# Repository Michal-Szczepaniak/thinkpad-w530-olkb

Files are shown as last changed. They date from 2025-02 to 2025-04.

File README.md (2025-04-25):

# Thinkpad OLKB Preonic keybaord pcb

Get it printed and enjoy.

USB can be connected in multiple ways:

- Directly into the MCU thanks to open space near it
- After soldering the bottom pads, via available pins next to the usb port
- After soldering the bottom pads and FPC connector, via FPC connector

USB can be fetched from multiple places, the lower end the laptop (x series) the less options so I'll list all the w530 options:

- Bluetooth connector, if you swapped wifi card for wifi+bt you aren't using the standalone bt so you can get usb from there
- msata, its next to the open hole for the usb, with msata to usb converter you can either just plug in short cable from msata directly to mcu (easiest possible connection) or you can cut the microusb end and solder it to pins or desolder the usb and route it with wires
- Smartcard fpc connector, it's located at the bottom middle of the motheboard next to the bios chips underneath the touchpad. Thats what the FPC connector on keyboard is for, you can buy 6 pin 0.5mm pitch FPC cable and connect it. Watch out though because it has 5V 15A unfused and if you short it you will instantly kill the laptop, but the keyboard has fuse which protects it, but only if something happens AFTER the fuse so isolate the fpc connector pins.
- Fingerprint/color sensor usb FPC, they're both just usb's on FPC tape, so you can use that, although they might not be directly pluggable into keyboard's FPC connector, I don't know their pinout as I was targetting the Smartcard FPC connector.

Power button is connected via mounting OG keyboard's FPC tape or soldering it, you can pick either option by soldering the pads next to the FPC pins. Make sure you pick correct option otherwise you can short something. Power button is also routed to the mcu pin in case you want that, although when laptop is off, they keyboard is off unless you route always-on 5V to it.

There are pins for connecting Framework touchpad, if you go this route, just wire them to the test pads on the Framework's touchpad and that's it. If you want to use Framework's touchpad and mount it by demeling the case then you need to break out the touchpad pcb extension.

There's hole for a keyboard mounting screw, M2x20 and use a nut to hold it down but don't overtighten it!

Oh also cake the bottom in electrical tape and make sure there are no pointy solder points, otherwise it will short out on the aluminum case which is less than ideal.

As of now the space above keyboard is not covered by anything which is KIIIIIIINDA sketchy but can be covered with electrical tape or simple 3D print. If you don't use the hole for usb cable that one can also be covered via electrical tape.

# 3D Printable blanks

Because the keyboard has gaping hole in the middle for the usb cable and also gaping hole above it, there are 3D printable blanks that can be put in place to protect anything below. Also if you decide to mod the touchpad I've included the touchpad buttons blank. [Blanks directory](https://github.com/Michal-Szczepaniak/thinkpad-w530-olkb)

# BOM 

- FPC 6PIN 0.5mm pitch, opposite side. Also please be careful because if you wire it incorrectly you'll instantly fry the motherboard.
- 6 pin FPC connector - DS1020-11-6VBT1-R
- Raspberry pi pico
- PG1425 switches
- Either THT or SMD diodes - THT you can handle, SMD 1N4148WS-DIO (SOD323F)
- Patience

# Palm rejection not working 

By default both framework touchpad and this keyboard are treated as external devices so we have to tell libinput that they're in fact not.

Create file `/etc/libinput/local-overrides.quirks` with content:
```
[Keyboards]
MatchUdevType=keyboard
MatchName=QMK Macroboard
AttrKeyboardIntegration=internal

[Touchpad]
MatchUdevType=touchpad
MatchName=QMK Macroboard Touchpad
AttrKeyboardIntegration=internal
```

And enable palm rejection. Voila!

# Gallery

## Schematic

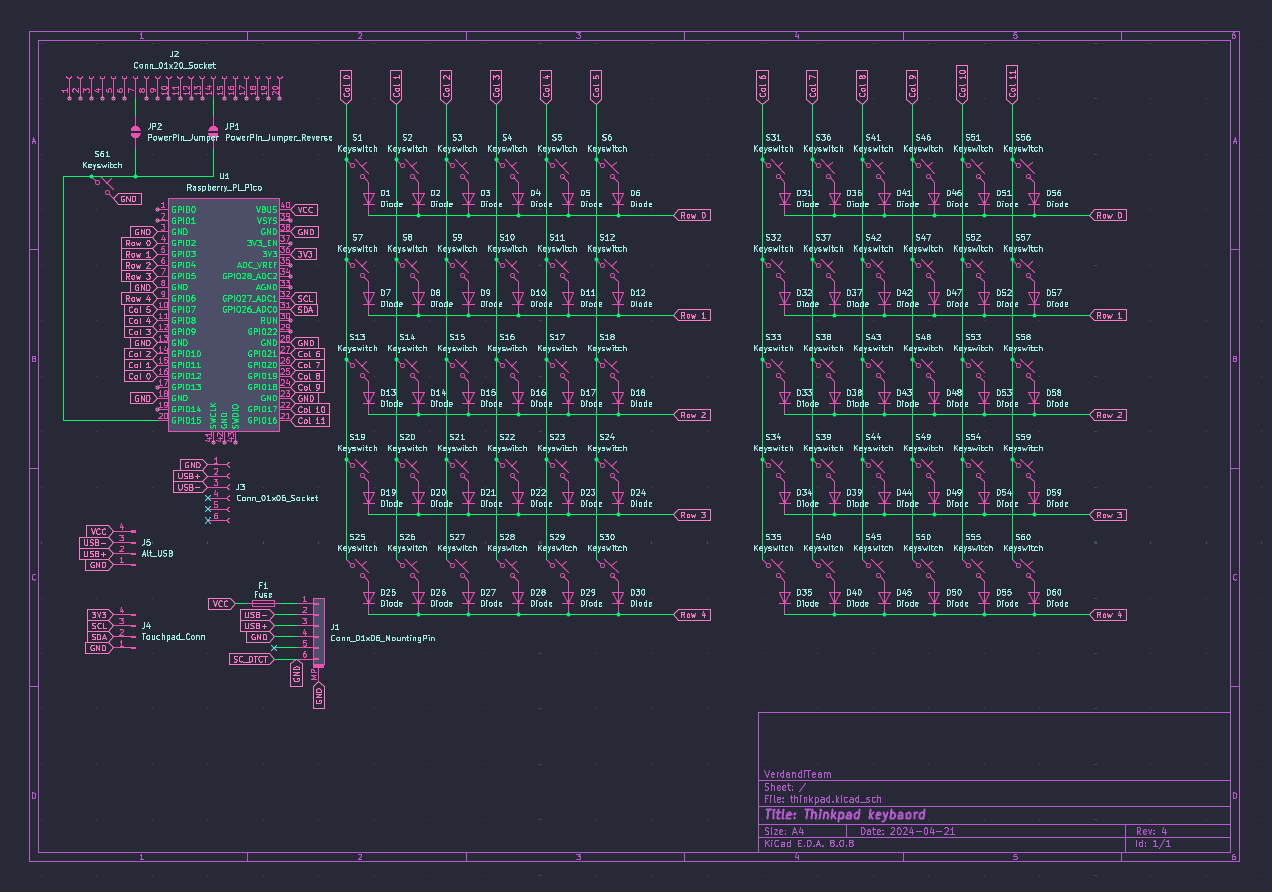
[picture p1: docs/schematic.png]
Schematic
 

## Board

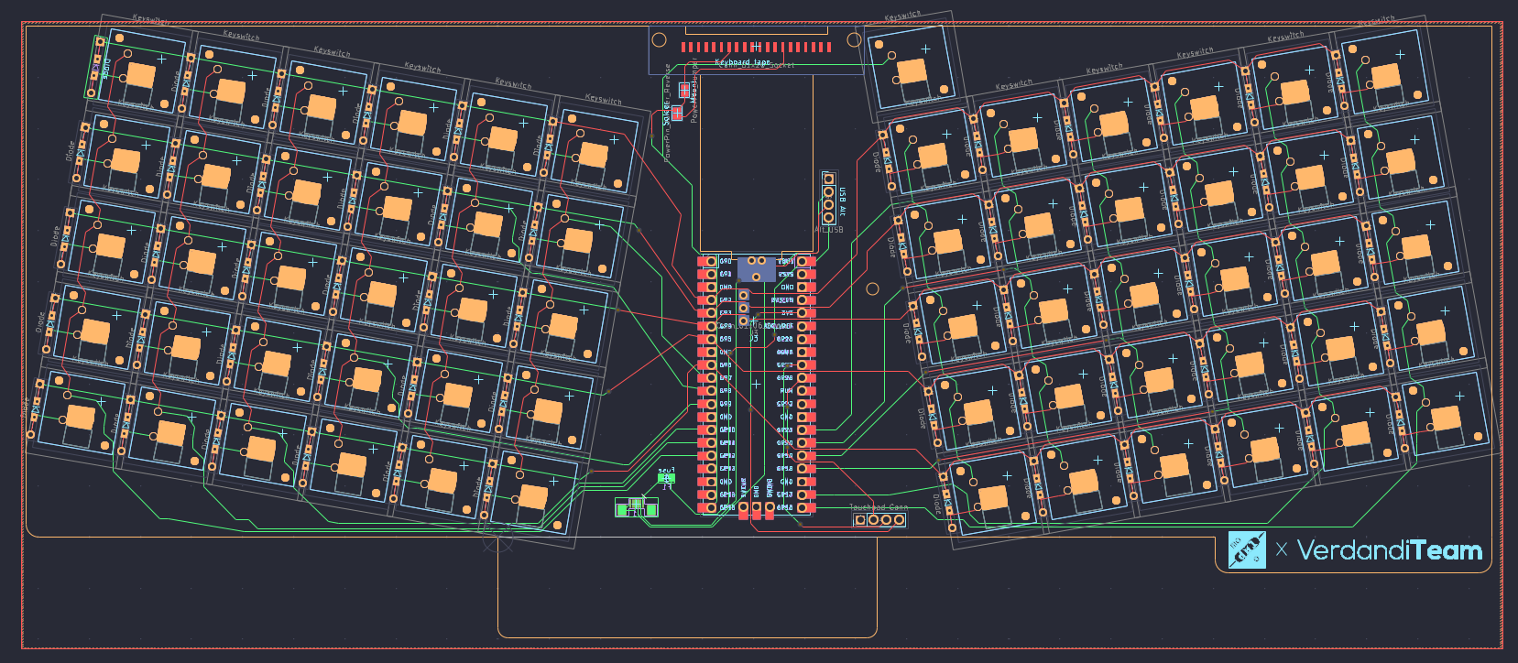
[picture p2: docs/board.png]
Board
 

## 3D View

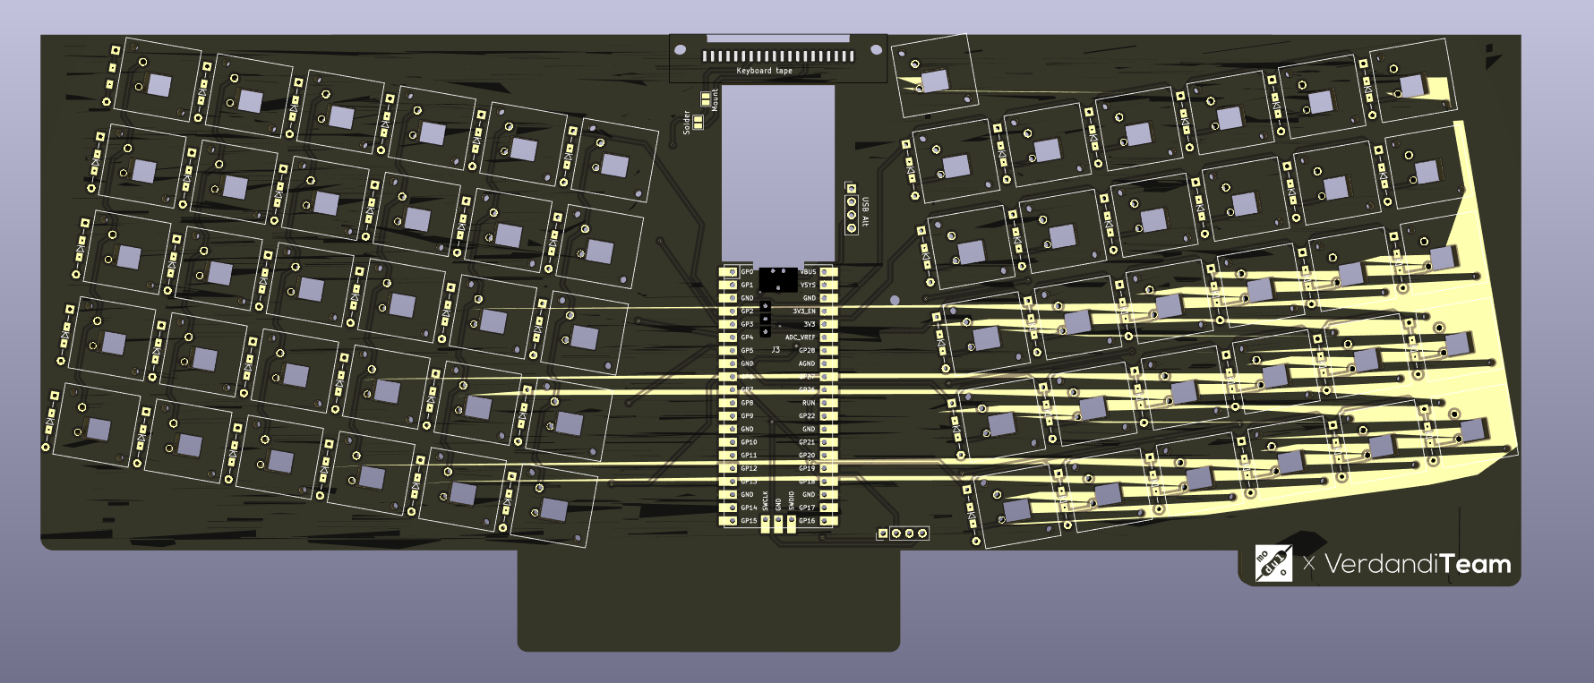
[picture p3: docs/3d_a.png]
 

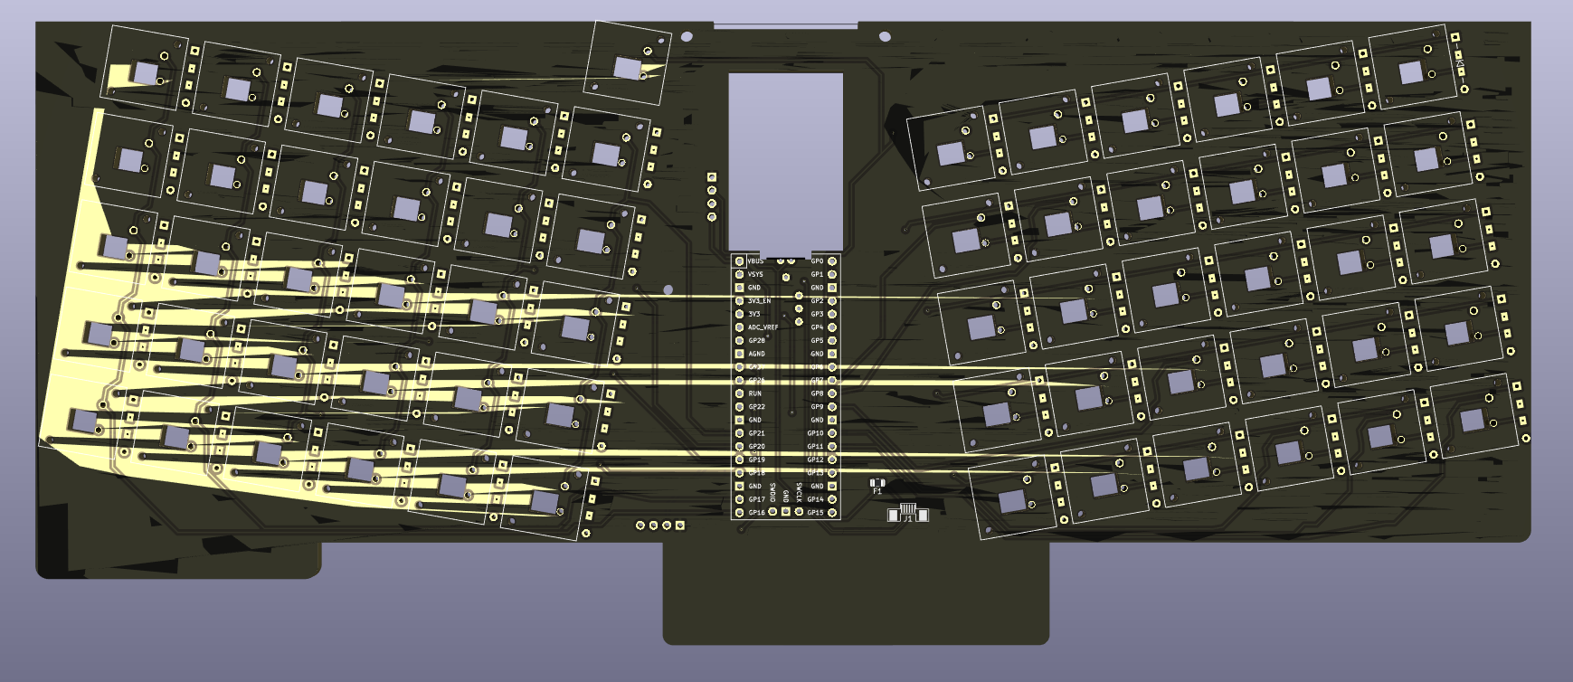
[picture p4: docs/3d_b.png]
 

## Real photo

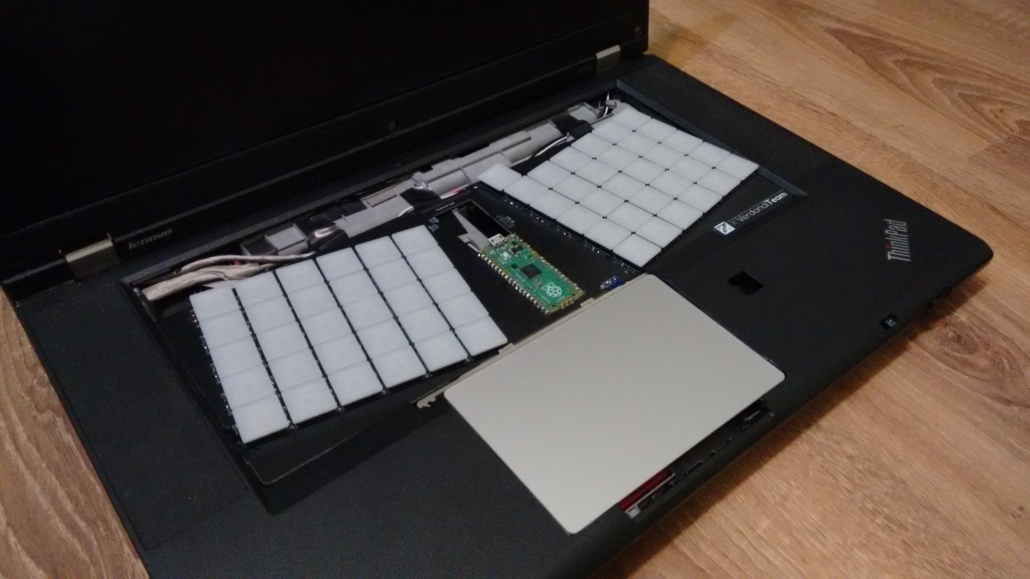
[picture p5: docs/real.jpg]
Real photo


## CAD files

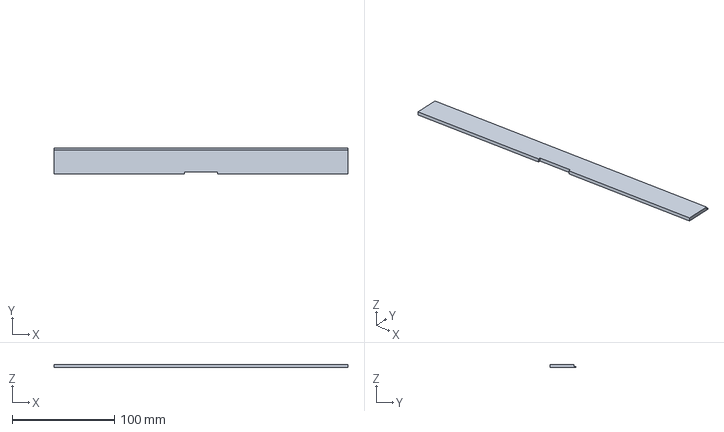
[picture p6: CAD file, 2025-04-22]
blanks/keyboard top blank-Body.3mf
287.0 x 25.0 x 3.00 mm

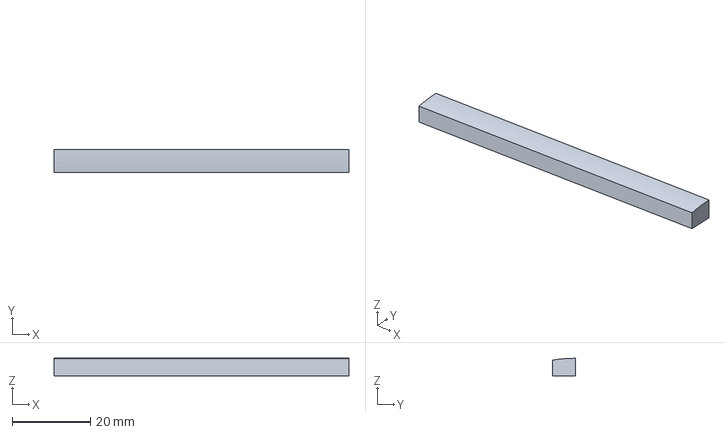
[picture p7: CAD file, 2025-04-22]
blanks/touchpad blank-Body.3mf
75.5 x 6.00 x 4.50 mm

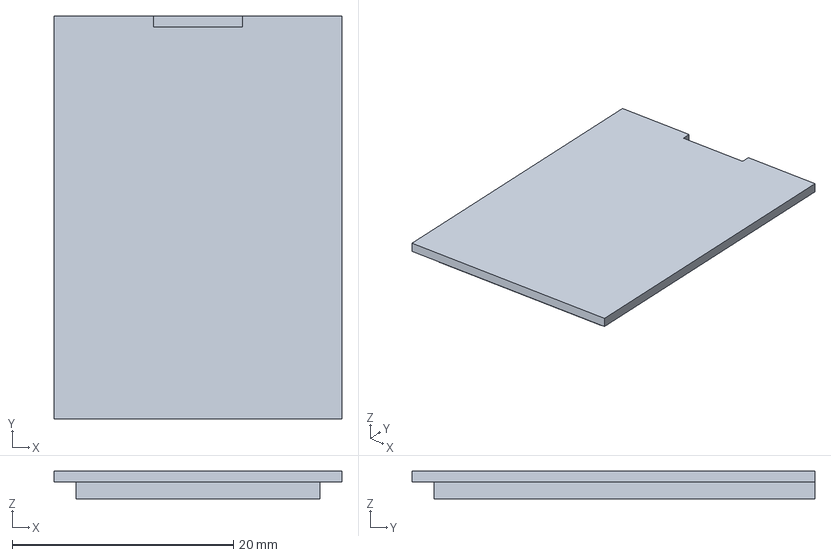
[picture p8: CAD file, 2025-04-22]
blanks/keyboard inner blank-Body.3mf
26.0 x 36.4 x 2.50 mm

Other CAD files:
blanks/keyboard top blank.FCStd
blanks/touchpad blank.FCStd
blanks/keyboard inner blank.FCStd

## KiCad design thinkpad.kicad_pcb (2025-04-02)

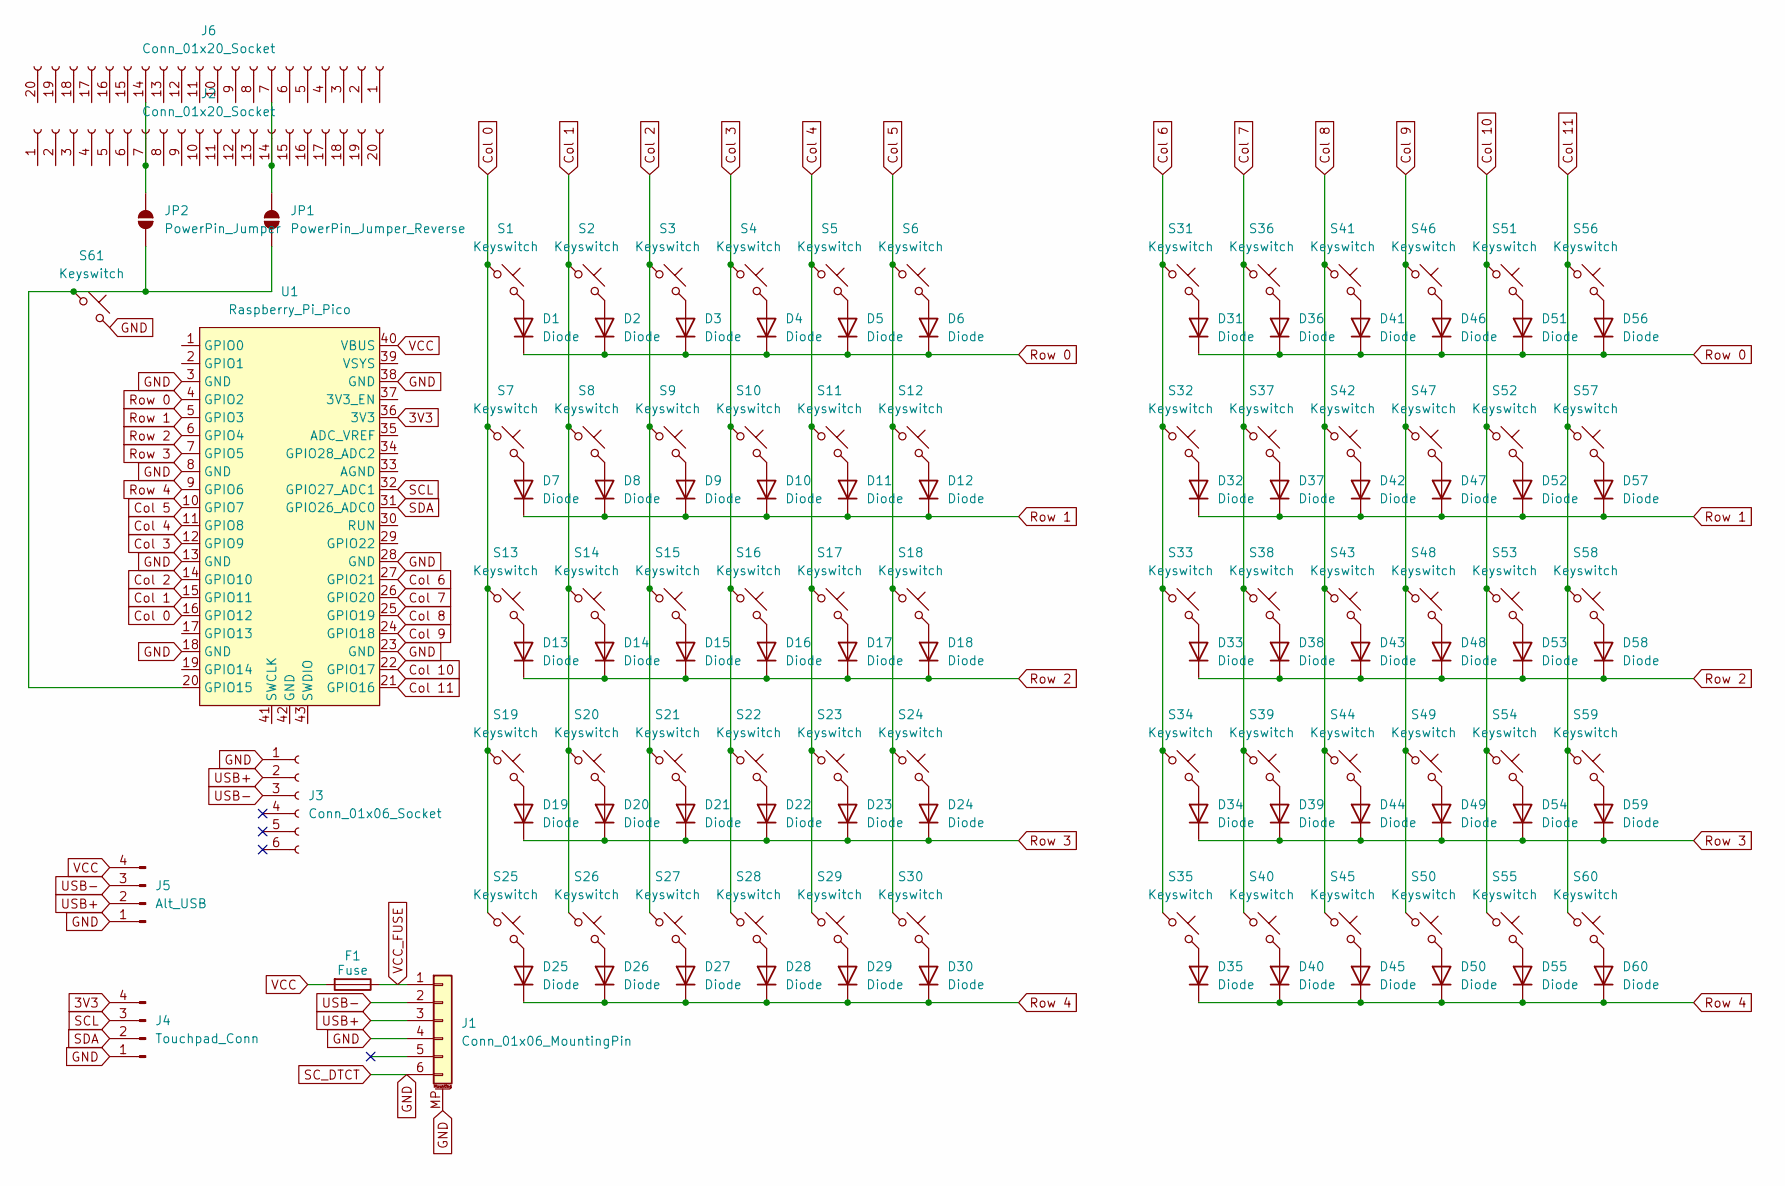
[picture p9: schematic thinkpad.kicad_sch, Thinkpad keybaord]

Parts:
D1, D2, D3, D4, D5, D6, D7, D8, D9, D10, D11, D12, D13, D14, D15, D16, D17, D18, D19, D20, D21, D22, D23, D24, D25, D26, D27, D28, D29, D30, D31, D32, D33, D34, D35, D36, D37, D38, D39, D40, D41, D42, D43, D44, D45, D46, D47, D48, D49, D50, D51, D52, D53, D54, D55, D56, D57, D58, D59, D60: Diode; Diode_SMD_THT2
F1: Fuse; Fuse_0805_2012Metric
J1: Conn_01x06_MountingPin; FPC_6
J2, J6: Conn_01x20_Socket; Thinkpad-keyboard-fpc
J3: Conn_01x06_Socket; pi pico usb
J4: Touchpad_Conn; PinHeader_1x04_P2.54mm_Vertical
J5: Alt_USB; PinHeader_1x04_P2.54mm_Vertical
JP1: PowerPin_Jumper_Reverse; SolderJumper-2_P1.3mm_Open_Pad1.0x1.5mm
JP2: PowerPin_Jumper; SolderJumper-2_P1.3mm_Open_Pad1.0x1.5mm
S1, S2, S3, S4, S5, S6, S7, S8, S9, S10, S11, S12, S13, S14, S15, S16, S17, S18, S19, S20, S21, S22, S23, S24, S25, S26, S27, S28, S29, S30, S31, S32, S33, S34, S35, S36, S37, S38, S39, S40, S41, S42, S43, S44, S45, S46, S47, S48, S49, S50, S51, S52, S53, S54, S55, S56, S57, S58, S59, S60, S61: Keyswitch; Kailh-PG1425-X-Switch
U1: Raspberry_Pi_Pico

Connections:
3V3: J4.4, U1.36 (3V3)
Col 0: S1.1, S7.1, S13.1, S19.1, S25.1, U1.16 (GPIO12)
Col 1: S2.1, S8.1, S14.1, S20.1, S26.1, U1.15 (GPIO11)
Col 2: S3.1, S9.1, S15.1, S21.1, S27.1, U1.14 (GPIO10)
Col 3: S4.1, S10.1, S16.1, S22.1, S28.1, U1.12 (GPIO9)
Col 4: S5.1, S11.1, S17.1, S23.1, S29.1, U1.11 (GPIO8)
Col 5: S6.1, S12.1, S18.1, S24.1, S30.1, U1.10 (GPIO7)
Col 6: S31.1, S32.1, S33.1, S34.1, S35.1, U1.27 (GPIO21)
Col 7: S36.1, S37.1, S38.1, S39.1, S40.1, U1.26 (GPIO20)
Col 8: S41.1, S42.1, S43.1, S44.1, S45.1, U1.25 (GPIO19)
Col 9: S46.1, S47.1, S48.1, S49.1, S50.1, U1.24 (GPIO18)
Col 10: S51.1, S52.1, S53.1, S54.1, S55.1, U1.22 (GPIO17)
Col 11: S56.1, S57.1, S58.1, S59.1, S60.1, U1.21 (GPIO16)
GND: J1.4, J1.6, J1.MP (MountPin), J3.1, J4.1, J5.1, S61.2, U1.3 (GND), U1.8 (GND), U1.13 (GND), U1.18 (GND), U1.23 (GND), U1.28 (GND), U1.38 (GND)
unnamed: D1.2 (A), S1.2
unnamed: D2.2 (A), S2.2
unnamed: D3.2 (A), S3.2
unnamed: D4.2 (A), S4.2
unnamed: D5.2 (A), S5.2
unnamed: D6.2 (A), S6.2
unnamed: D7.2 (A), S7.2
unnamed: D8.2 (A), S8.2
unnamed: D9.2 (A), S9.2
unnamed: D10.2 (A), S10.2
unnamed: D11.2 (A), S11.2
unnamed: D12.2 (A), S12.2
unnamed: D13.2 (A), S13.2
unnamed: D14.2 (A), S14.2
unnamed: D15.2 (A), S15.2
unnamed: D16.2 (A), S16.2
unnamed: D17.2 (A), S17.2
unnamed: D18.2 (A), S18.2
unnamed: D19.2 (A), S19.2
unnamed: D20.2 (A), S20.2
unnamed: D21.2 (A), S21.2
unnamed: D22.2 (A), S22.2
unnamed: D23.2 (A), S23.2
unnamed: D24.2 (A), S24.2
unnamed: D25.2 (A), S25.2
unnamed: D26.2 (A), S26.2
unnamed: D27.2 (A), S27.2
unnamed: D28.2 (A), S28.2
unnamed: D29.2 (A), S29.2
unnamed: D30.2 (A), S30.2
unnamed: D31.2 (A), S31.2
unnamed: D32.2 (A), S32.2
unnamed: D33.2 (A), S33.2
unnamed: D34.2 (A), S34.2
unnamed: D35.2 (A), S35.2
unnamed: D36.2 (A), S36.2
unnamed: D37.2 (A), S37.2
unnamed: D38.2 (A), S38.2
unnamed: D39.2 (A), S39.2
unnamed: D40.2 (A), S40.2
unnamed: D41.2 (A), S41.2
unnamed: D42.2 (A), S42.2
unnamed: D43.2 (A), S43.2
unnamed: D44.2 (A), S44.2
unnamed: D45.2 (A), S45.2
unnamed: D46.2 (A), S46.2
unnamed: D47.2 (A), S47.2
unnamed: D48.2 (A), S48.2
unnamed: D49.2 (A), S49.2
unnamed: D50.2 (A), S50.2
unnamed: D51.2 (A), S51.2
unnamed: D52.2 (A), S52.2
unnamed: D53.2 (A), S53.2
unnamed: D54.2 (A), S54.2
unnamed: D55.2 (A), S55.2
unnamed: D56.2 (A), S56.2
unnamed: D57.2 (A), S57.2
unnamed: D58.2 (A), S58.2
unnamed: D59.2 (A), S59.2
unnamed: D60.2 (A), S60.2
unnamed: J2.7, J6.14, JP2.2 (B)
unnamed: J2.14, J6.7, JP1.2 (B)
unnamed: JP1.1 (A), JP2.1 (A), S61.1, U1.20 (GPIO15)
Row 0: D1.1 (K), D2.1 (K), D3.1 (K), D4.1 (K), D5.1 (K), D6.1 (K), D31.1 (K), D36.1 (K), D41.1 (K), D46.1 (K), D51.1 (K), D56.1 (K), U1.4 (GPIO2)
Row 1: D7.1 (K), D8.1 (K), D9.1 (K), D10.1 (K), D11.1 (K), D12.1 (K), D32.1 (K), D37.1 (K), D42.1 (K), D47.1 (K), D52.1 (K), D57.1 (K), U1.5 (GPIO3)
Row 2: D13.1 (K), D14.1 (K), D15.1 (K), D16.1 (K), D17.1 (K), D18.1 (K), D33.1 (K), D38.1 (K), D43.1 (K), D48.1 (K), D53.1 (K), D58.1 (K), U1.6 (GPIO4)
Row 3: D19.1 (K), D20.1 (K), D21.1 (K), D22.1 (K), D23.1 (K), D24.1 (K), D34.1 (K), D39.1 (K), D44.1 (K), D49.1 (K), D54.1 (K), D59.1 (K), U1.7 (GPIO5)
Row 4: D25.1 (K), D26.1 (K), D27.1 (K), D28.1 (K), D29.1 (K), D30.1 (K), D35.1 (K), D40.1 (K), D45.1 (K), D50.1 (K), D55.1 (K), D60.1 (K), U1.9 (GPIO6)
SCL: J4.3, U1.32 (GPIO27_ADC1)
SDA: J4.2, U1.31 (GPIO26_ADC0)
USB+: J1.3, J3.2, J5.2
USB-: J1.2, J3.3, J5.3
VCC: F1.2, J5.4, U1.40 (VBUS)
VCC_FUSE: F1.1, J1.1

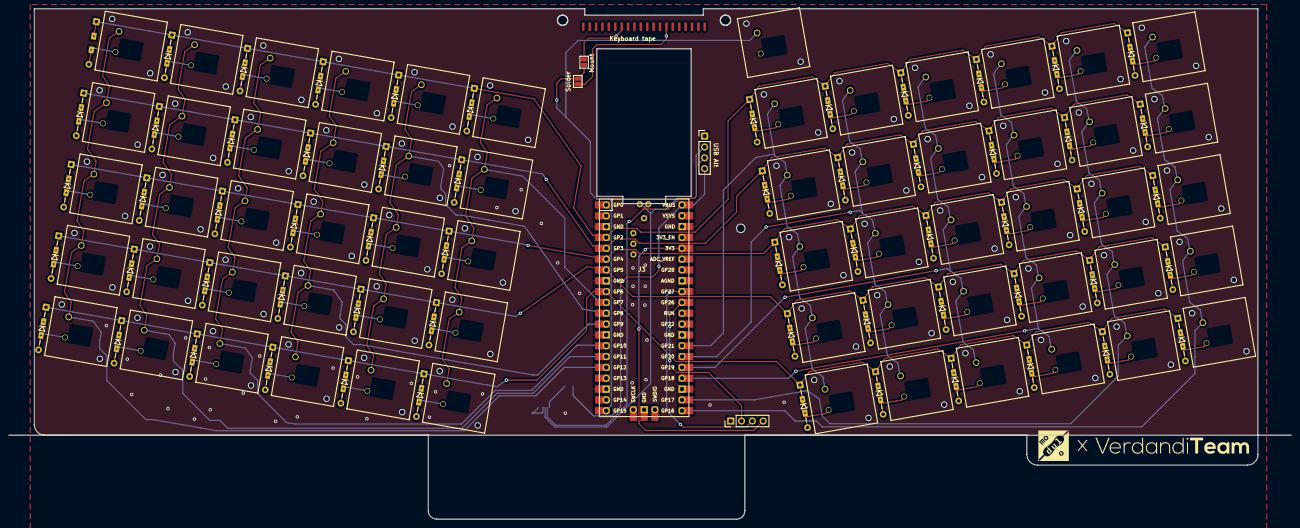
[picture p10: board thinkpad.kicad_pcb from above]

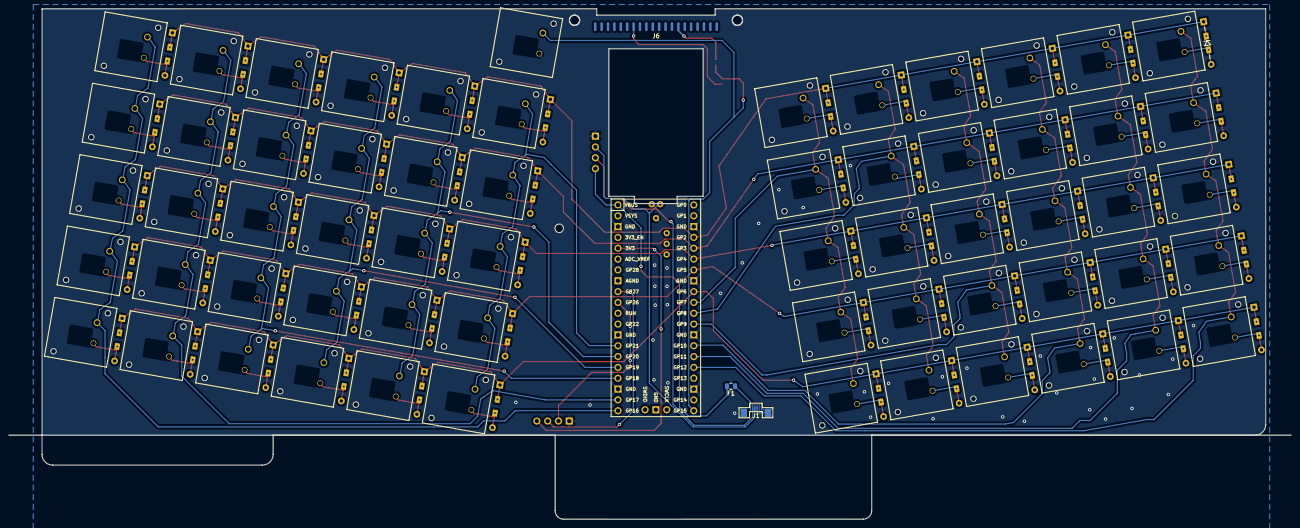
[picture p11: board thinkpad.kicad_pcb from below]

Board: 2 copper layers, 300.8 x 119.7 mm, 131 parts (4 on the bottom side), 88 nets.

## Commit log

2023-11-22 Fix gnd
    [thinkpad.kicad_pcb, thinkpad.kicad_sch]
2023-11-29 Made space for touchpad, fixed connection of cols, added pads for touchpad i2c
    [thinkpad.kicad_pcb, thinkpad.kicad_sch]
2023-11-29 Give 3V3 to touchpad
    [thinkpad.kicad_pcb, thinkpad.kicad_sch]
2024-04-22 Fix issue with usb and aligning the tape
    [thinkpad.kicad_pcb, thinkpad.kicad_sch]
2024-12-21 Change switches
    [thinkpad.kicad_pcb, thinkpad.kicad_sch]
2025-02-25 Fix issues and add breakable touchpad
    [thinkpad.kicad_pcb]
2025-02-26 filled zones set to no-island, vias added to make ground fills appear in more places (mostly aesthetic), keeb connector duuplicated, drc clean, unconnected 0, life is good
    [thinkpad.kicad_pcb, thinkpad.kicad_sch]
2025-04-02 Update BOM
    [thinkpad.kicad_pcb]
2025-04-22 Add blanks
    [keyboard inner blank-Body.3mf, keyboard inner blank.FCStd, keyboard top blank-Body.3mf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]
